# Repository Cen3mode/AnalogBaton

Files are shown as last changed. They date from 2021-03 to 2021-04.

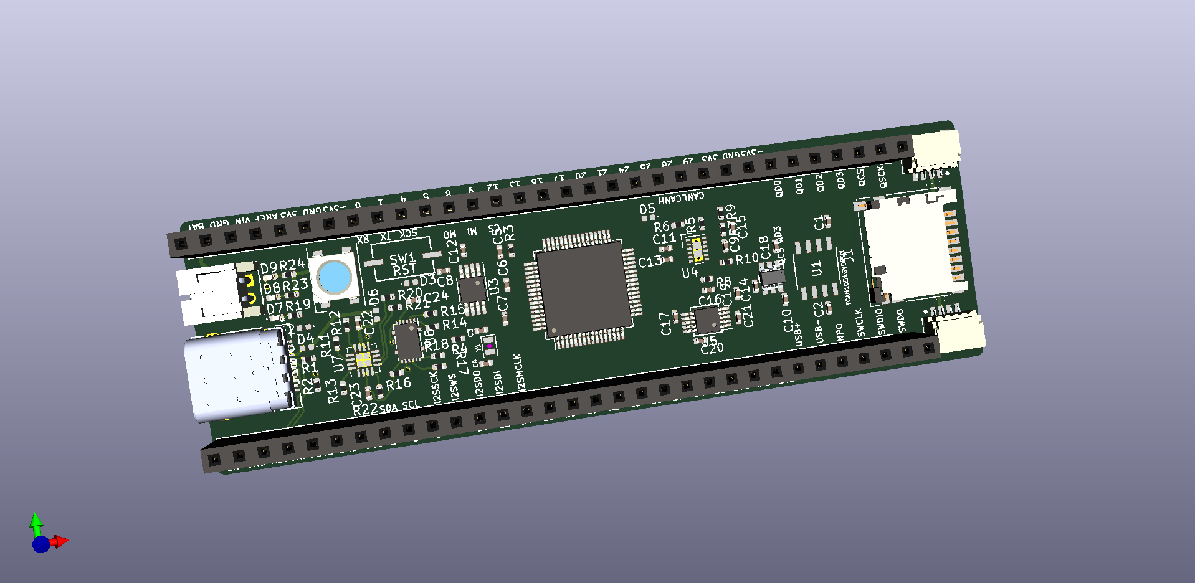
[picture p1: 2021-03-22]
pcbDesign/ATSAME51J18A-devboard.png

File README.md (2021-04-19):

TO DO:
	redo GPIO layout,
	redo SD card slot,
	get rid of CAN bus connector (leave broken out on pins),
	redo power from charge pumps to LDOs where possible for simplicity,
	make the board smaller,
	get rid of the cristall (using internal oscillator),
	choose USB-C port with only single row of pins,
	add M3 mounting holes,
	reconfigure charger and fuel gauge,
	add QSPI flash,

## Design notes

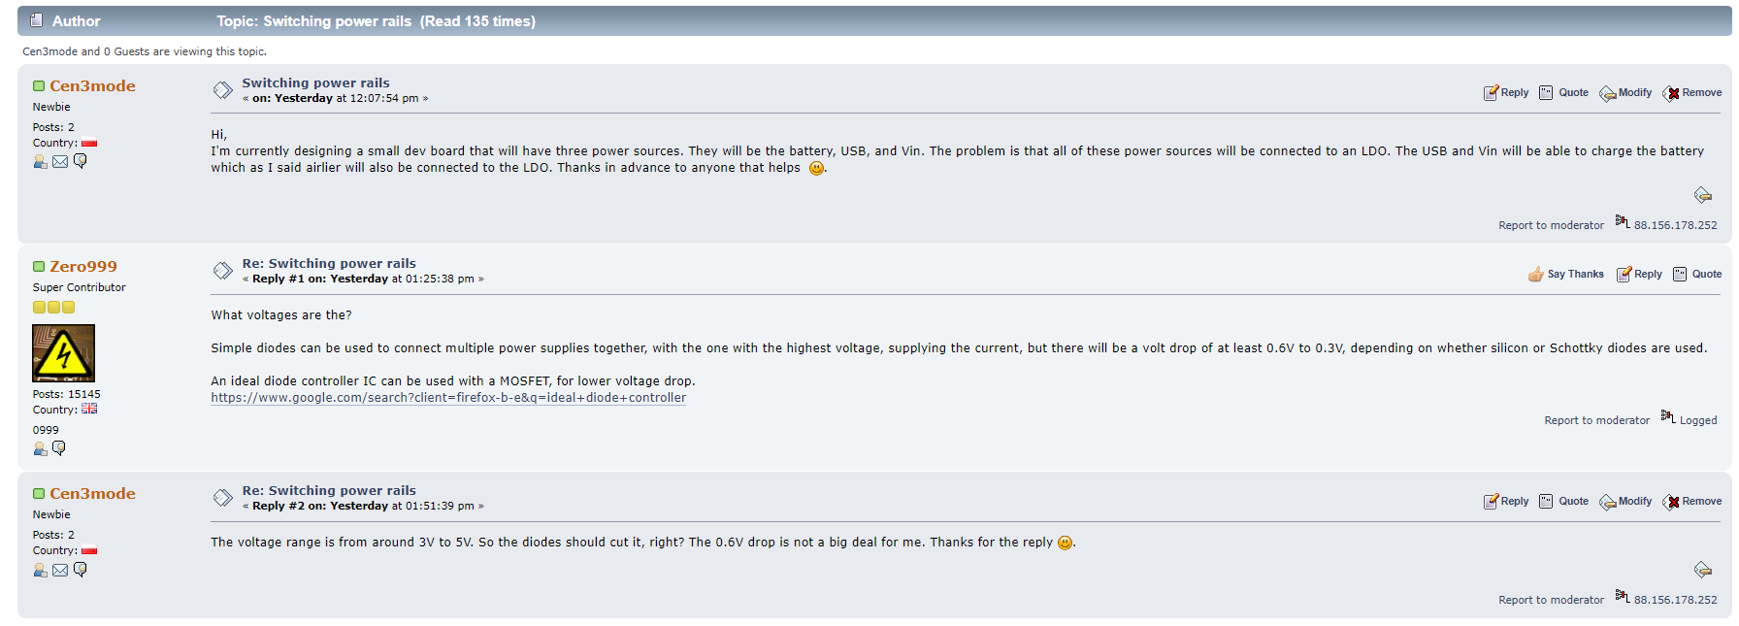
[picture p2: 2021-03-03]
forumDiscussionss/switchingPowerRails.PNG

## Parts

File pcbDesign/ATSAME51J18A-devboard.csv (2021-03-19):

Id | Oznaczenie | Obudowa | Ilość | Oznaczenie | Dostawca i numer artykułu
1 | U5 | MSOP-10_3x3mm_P0.5mm | 1 | TPS60501DGS | TPS60501DGSR
2 | J4 | JST_S2B-PH-K-S(LF)(SN) | 1 | S2B-PH-K-S(LF)(SN) | S2B-PH-K-S(LF)(SN)
3 | J2 | 12401598E4-2A | 1 | USB C | 12401598E4#2A
4 | IC1 | SOT95P280X100-6N | 1 | MP9361DJ-LF-P | MP9361DJ-LF-P
5 | SW1 | PTS636 SM25F SMTR LFS | 1 | RST | PTS636 SMG25J SMTR LFS
6 | J11,J7 | PinSocket_1x32_P2.54mm_Vertical | 2 | Conn_01x32_Male | 61303211121
7 | U2 | TQFP-64_10x10mm_P0.5mm | 1 | ATSAME51J18A-A | ATSAME51J18A-AUT
8 | J3 | JST_SM04B-SRSS-TB(LF)(SN) | 1 | QWIIC | SM04B-SRSS-TB(LF)(SN)
9 | R24,R23,R22,R21,R20,R5,R19,R18,R17,R6,R4,R3 | R_0402_1005Metric | 12 | 10k | RMCF0402JT10K0
10 | D9 | LED_0402_1005Metric | 1 | CHRG | APHHS1005CGCK
11 | Y1 | Crystal_SMD_2012-2Pin_2.0x1.2mm | 1 | 32.768 | ECS-.327-12.5-12-TR
12 | D8 | LED_0402_1005Metric | 1 | PWR | APHHS1005CGCK
13 | J10 | JST_SM04B-SRSS-TB(LF)(SN) | 1 | CAN | SM04B-SRSS-TB(LF)(SN)
14 | U8 | Texas_S-PDSO-N12 | 1 | BQ27441DRZR-G1B | BQ27441DRZR-G1B
15 | U7 | VQFN-16-1EP_3x3mm_P0.5mm_EP1.6x1.6mm | 1 | BQ24074RGT | BQ24074RGTT
16 | U4 | WSON-12-1EP_3x2mm_P0.5mm_EP1x2.65_ThermalVias | 1 | LM27762 | LM27762DSST
17 | U3 | MSOP-8_3x3mm_P0.65mm | 1 | MIC5219-5.0YMM | MIC5219-5.0YMM
18 | U1 | TCAN1051GVDRQ1 | 1 | TCAN1051GVDRQ1 | TCAN1051HVD
19 | R16 | R_0402_1005Metric | 1 | 0.01 | PE0402FRF070R01L
20 | R15,R14,R2,R1 | R_0402_1005Metric | 4 | 5.1k | RC0402FR-075K1L
21 | R13 | R_0402_1005Metric | 1 | 1.13k | RC0402FR-071K13L
22 | R12 | R_0402_1005Metric | 1 | 1.18k | RC0402FR-071K18L
23 | R11 | R_0402_1005Metric | 1 | 46.4k | RK73H1ETTP4642F
24 | R10,R9 | R_0402_1005Metric | 2 | 50k | RC1005F4992CS
25 | R8,R7 | R_0402_1005Metric | 2 | 87.5k | RC0402FR-0786K6L
27 | J1 | microSD_HC_Hirose_DM3D-SF | 1 | Micro_SD_Card | 5031821852
28 | D7 | LED_0402_1005Metric | 1 | LED | APHHS1005CGCK
29 | D6,D5,D4,D3,D2 | D_0402_1005Metric | 5 | D_Schottky | VSKY05301006-G4-08
30 | D1 | LED_WS2812B_PLCC4_5.0x5.0mm_P3.2mm | 1 | WS2812B | COM-16347
31 | C24,C14,C9,C8 | C_0402_1005Metric | 4 | 0.47u | GMC04X5R474K16NT
32 | C23,C22,C19,C13,C11 | C_0402_1005Metric | 5 | 4.7u | C1005X5R0J475M050BC
33 | C21,C17,C6,C5 | C_0402_1005Metric | 4 | 1u | CC0402KRX5R5BB105
34 | C20,C4,C3 | C_0402_1005Metric | 3 | 22u | CL05A226MQ6ZUN8
35 | C18 | C_0402_1005Metric | 1 | 10u | CL05A106MQ5NUNC
36 | C16,C15,C12,C10 | C_0402_1005Metric | 4 | 2.2u | C1005X7S1A225K050BC
37 | C7 | C_0402_1005Metric | 1 | 500n | GRM155R61A564KE15D
38 | C2,C1 | C_0402_1005Metric | 2 | 100n | GRM155R71C104KA88J

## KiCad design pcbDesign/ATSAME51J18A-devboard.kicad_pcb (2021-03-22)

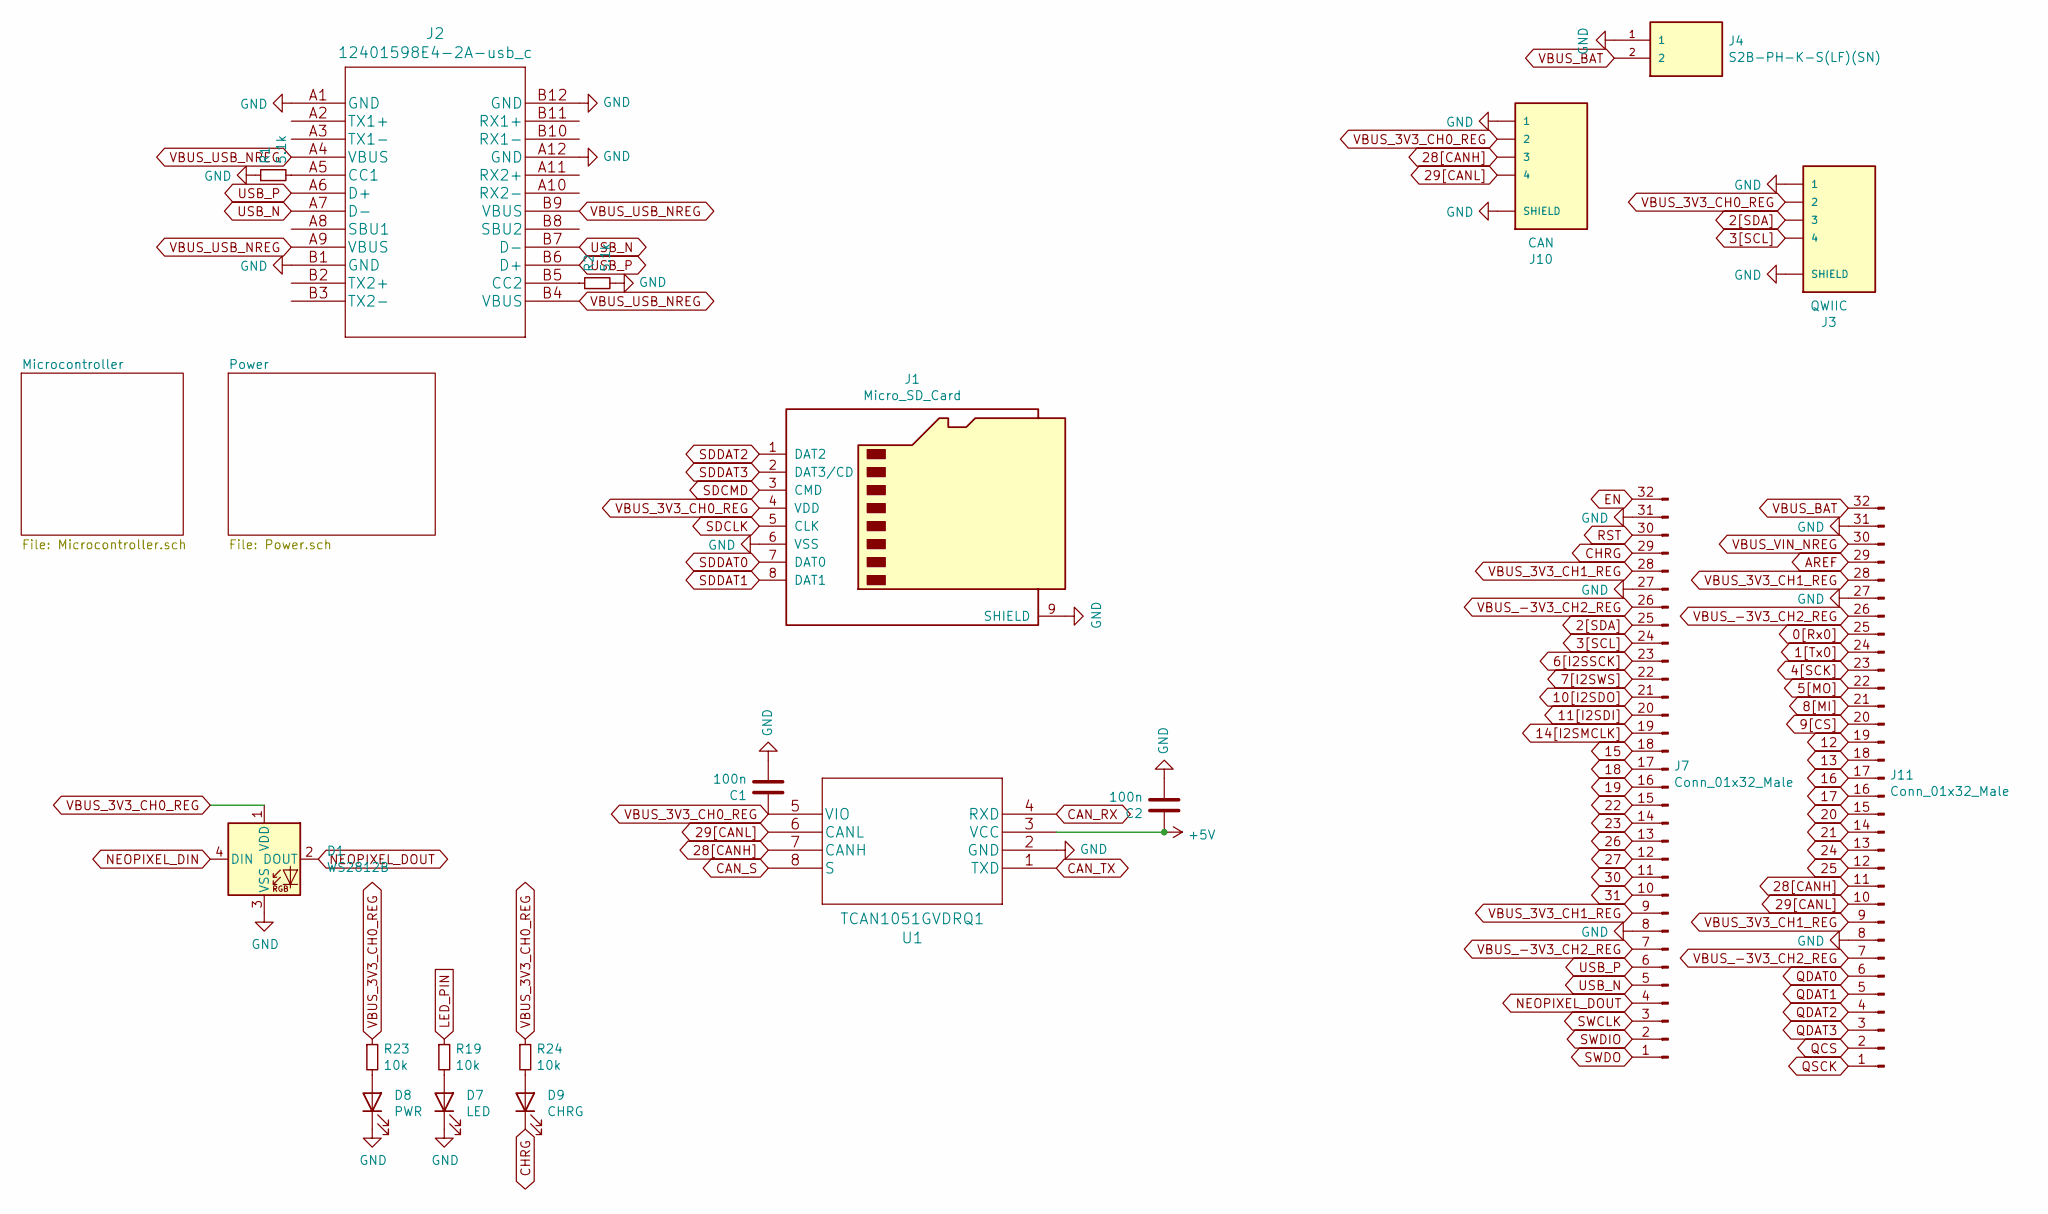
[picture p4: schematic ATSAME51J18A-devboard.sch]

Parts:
C1, C2: 100n; C_0402_1005Metric
D1: WS2812B; LED_WS2812B_PLCC4_5.0x5.0mm_P3.2mm
D7: LED; LED_0402_1005Metric
D8: PWR; LED_0402_1005Metric
D9: CHRG; LED_0402_1005Metric
J1: Micro_SD_Card; microSD_HC_Hirose_DM3D-SF
J2: 12401598E4-2A-usb_c; 12401598E4-2A
J3: QWIIC; JST_SM04B-SRSS-TB(LF)(SN)
J4: S2B-PH-K-S(LF)(SN); JST_S2B-PH-K-S(LF)(SN)
J7, J11: Conn_01x32_Male; PinSocket_1x32_P2.54mm_Vertical
J10: CAN; JST_SM04B-SRSS-TB(LF)(SN)
R1, R2: 5.1k; R_0402_1005Metric
R19, R23, R24: 10k; R_0402_1005Metric
U1: TCAN1051GVDRQ1

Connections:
0[Rx0]: J11.25; also elsewhere on the board
1[Tx0]: J11.24; also elsewhere on the board
2[SDA]: J3.3, J7.25; also elsewhere on the board
3[SCL]: J3.4, J7.24; also elsewhere on the board
4[SCK]: J1.5 (CLK), J11.23; also elsewhere on the board
5[MO]: J1.3 (CMD), J11.22; also elsewhere on the board
6[I2SSCK]: J7.23; also elsewhere on the board
7[I2SWS]: J7.22; also elsewhere on the board
8[MI]: J1.7 (DAT0), J11.21; also elsewhere on the board
9[CS]: J11.20; also elsewhere on the board
10[I2SDO]: J7.21; also elsewhere on the board
11[I2SDI]: J7.20; also elsewhere on the board
12: J11.19; also elsewhere on the board
13: J11.18, R19.1; also elsewhere on the board
14[I2SMCLK]: J7.19; also elsewhere on the board
15: J7.18; also elsewhere on the board
16: J11.17; also elsewhere on the board
17: J11.16; also elsewhere on the board
18: J7.17; also elsewhere on the board
19: J7.16; also elsewhere on the board
20: J11.15; also elsewhere on the board
21: J11.14; also elsewhere on the board
22: J7.15; also elsewhere on the board
23: J7.14; also elsewhere on the board
24: J11.13; also elsewhere on the board
25: J11.12; also elsewhere on the board
26: J7.13; also elsewhere on the board
27: J7.12; also elsewhere on the board
28[CANH]: J10.3, J11.11, U1.7 (CANH)
29[CANL]: J10.4, J11.10, U1.6 (CANL)
30: J7.11; also elsewhere on the board
31: J7.10; also elsewhere on the board
+5V: C2.2, U1.3 (VCC); also elsewhere on the board
AREF: J11.29; also elsewhere on the board
CAN_RX: U1.4 (RXD); also elsewhere on the board
CAN_S: U1.8 (S); also elsewhere on the board
CAN_TX: U1.1 (TXD); also elsewhere on the board
CHRG: D9.1 (K), J7.29; also elsewhere on the board
EN: J7.32; also elsewhere on the board
GND: C1.1, C2.1, D1.3 (VSS), D7.1 (K), D8.1 (K), J1.6 (VSS), J1.9 (SHIELD), J2.A1 (GND), J2.A12 (GND), J2.B1 (GND), J2.B12 (GND), J3.1, J3.S1 (SHIELD), J3.S2 (SHIELD), J4.1, J7.8, J7.27, J7.31, J10.1, J10.S1 (SHIELD), J10.S2 (SHIELD), J11.8, J11.27, J11.31, R1.1, R2.2, U1.2 (GND); also elsewhere on the board
NEOPIXEL_DIN: D1.4 (DIN); also elsewhere on the board
NEOPIXEL_DOUT: D1.2 (DOUT), J7.4
unnamed: D7.2 (A), R19.2
unnamed: D8.2 (A), R23.2
unnamed: D9.2 (A), R24.2
unnamed: J2.A5 (CC1), R1.2
unnamed: J2.B5 (CC2), R2.1
QCS: J11.2; also elsewhere on the board
QDAT0: J11.6; also elsewhere on the board
QDAT1: J11.5; also elsewhere on the board
QDAT2: J11.4; also elsewhere on the board
QDAT3: J11.3; also elsewhere on the board
QSCK: J11.1; also elsewhere on the board
RST: J7.30; also elsewhere on the board
SDDAT3: J1.2 (DAT3/CD); also elsewhere on the board
SWCLK: J7.3; also elsewhere on the board
SWDIO: J7.2; also elsewhere on the board
SWDO: J7.1; also elsewhere on the board
USB_N: J2.A7 (D-), J2.B7 (D-), J7.5; also elsewhere on the board
USB_P: J2.A6 (D+), J2.B6 (D+), J7.6; also elsewhere on the board
VBUS_3V3_CH0_REG: C1.2, D1.1 (VDD), J1.4 (VDD), J3.2, J10.2, R23.1, R24.1, U1.5 (VIO); also elsewhere on the board
VBUS_3V3_CH1_REG: J7.9, J7.28, J11.9, J11.28; also elsewhere on the board
VBUS_-3V3_CH2_REG: J7.7, J7.26, J11.7, J11.26; also elsewhere on the board
VBUS_BAT: J4.2, J11.32; also elsewhere on the board
VBUS_USB_NREG: J2.A4 (VBUS), J2.A9 (VBUS), J2.B4 (VBUS), J2.B9 (VBUS); also elsewhere on the board
VBUS_VIN_NREG: J11.30; also elsewhere on the board

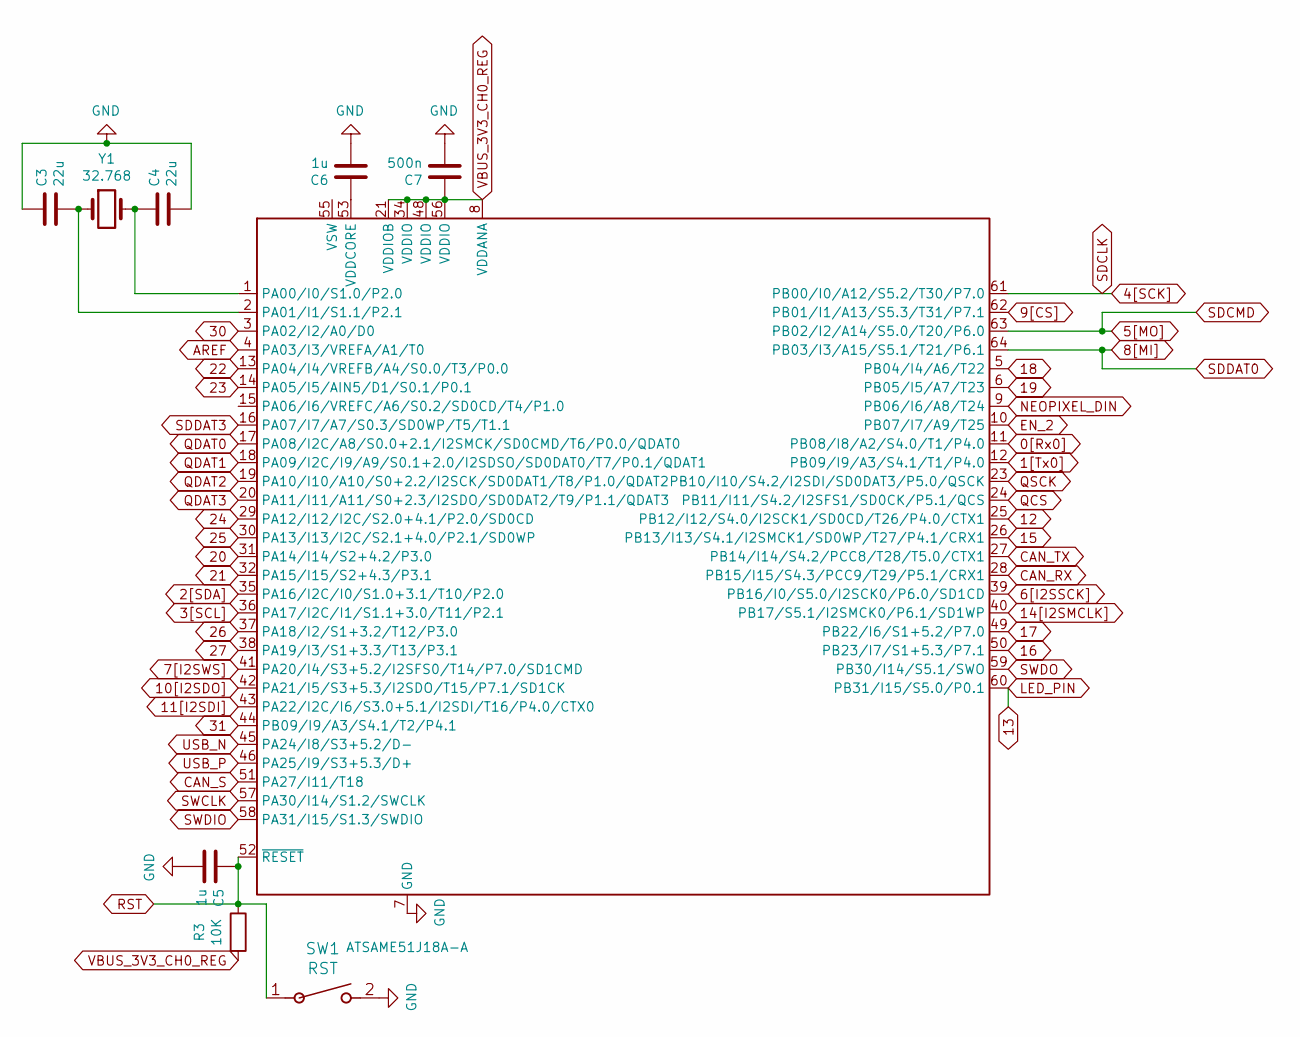
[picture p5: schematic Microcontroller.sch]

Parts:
C3, C4: 22u; C_0402_1005Metric
C5, C6: 1u; C_0402_1005Metric
C7: 500n; C_0402_1005Metric
R3: 10K; R_0402_1005Metric
SW1: RST; PTS636 SM25F SMTR LFS
U2: ATSAME51J18A-A; TQFP-64_10x10mm_P0.5mm
Y1: 32.768; Crystal_SMD_2012-2Pin_2.0x1.2mm

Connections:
0[Rx0]: U2.11 (PB08/I8/A2/S4.0/T1/P4.0); also elsewhere on the board
1[Tx0]: U2.12 (PB09/I9/A3/S4.1/T1/P4.0); also elsewhere on the board
2[SDA]: U2.35 (PA16/I2C/I0/S1.0+3.1/T10/P2.0); also elsewhere on the board
3[SCL]: U2.36 (PA17/I2C/I1/S1.1+3.0/T11/P2.1); also elsewhere on the board
4[SCK]: U2.61 (PB00/I0/A12/S5.2/T30/P7.0); also elsewhere on the board
5[MO]: U2.63 (PB02/I2/A14/S5.0/T20/P6.0); also elsewhere on the board
6[I2SSCK]: U2.39 (PB16/I0/S5.0/I2SCK0/P6.0/SD1CD); also elsewhere on the board
7[I2SWS]: U2.41 (PA20/I4/S3+5.2/I2SFS0/T14/P7.0/SD1CMD); also elsewhere on the board
8[MI]: U2.64 (PB03/I3/A15/S5.1/T21/P6.1); also elsewhere on the board
9[CS]: U2.62 (PB01/I1/A13/S5.3/T31/P7.1); also elsewhere on the board
10[I2SDO]: U2.42 (PA21/I5/S3+5.3/I2SDO/T15/P7.1/SD1CK); also elsewhere on the board
11[I2SDI]: U2.43 (PA22/I2C/I6/S3.0+5.1/I2SDI/T16/P4.0/CTX0); also elsewhere on the board
12: U2.25 (PB12/I12/S4.0/I2SCK1/SD0CD/T26/P4.0/CTX1); also elsewhere on the board
13: U2.60 (PB31/I15/S5.0/P0.1); also elsewhere on the board
14[I2SMCLK]: U2.40 (PB17/S5.1/I2SMCK0/P6.1/SD1WP); also elsewhere on the board
15: U2.26 (PB13/I13/S4.1/I2SMCK1/SD0WP/T27/P4.1/CR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); also elsewhere on the board
16: U2.50 (PB23/I7/S1+5.3/P7.1); also elsewhere on the board
17: U2.49 (PB22/I6/S1+5.2/P7.0); also elsewhere on the board
18: U2.5 (PB04/I4/A6/T22); also elsewhere on the board
19: U2.6 (PB05/I5/A7/T23); also elsewhere on the board
20: U2.31 (PA14/I14/S2+4.2/P3.0); also elsewhere on the board
21: U2.32 (PA15/I15/S2+4.3/P3.1); also elsewhere on the board
22: U2.13 (PA04/I4/VREFB/A4/S0.0/T3/P0.0); also elsewhere on the board
23: U2.14 (PA05/I5/AIN5/D1/S0.1/P0.1); also elsewhere on the board
24: U2.29 (PA12/I12/I2C/S2.0+4.1/P2.0/SD0CD); also elsewhere on the board
25: U2.30 (PA13/I13/I2C/S2.1+4.0/P2.1/SD0WP); also elsewhere on the board
26: U2.37 (PA18/I2/S1+3.2/T12/P3.0); also elsewhere on the board
27: U2.38 (PA19/I3/S1+3.3/T13/P3.1); also elsewhere on the board
30: U2.3 (PA02/I2/A0/D0); also elsewhere on the board
31: U2.44 (PB09/I9/A3/S4.1/T2/P4.1); also elsewhere on the board
AREF: U2.4 (PA03/I3/VREFA/A1/T0); also elsewhere on the board
CAN_RX: U2.28 (PB15/I15/S4.3/PCC9/T29/P5.1/CRX1); also elsewhere on the board
CAN_S: U2.51 (PA27/I11/T18); also elsewhere on the board
CAN_TX: U2.27 (PB14/I14/S4.2/PCC8/T28/T5.0/CTX1); also elsewhere on the board
EN_2: U2.10 (PB07/I7/A9/T25); also elsewhere on the board
GND: C3.2, C4.1, C5.1, C6.1, C7.1, SW1.2, U2.7 (GND), U2.22 (GND), U2.33 (GND), U2.47 (GND), U2.54 (GND); also elsewhere on the board
NEOPIXEL_DIN: U2.9 (PB06/I6/A8/T24); also elsewhere on the board
unnamed: C3.1, U2.2 (PA01/I1/S1.1/P2.1), Y1.1
unnamed: C4.2, U2.1 (PA00/I0/S1.0/P2.0), Y1.2
unnamed: C6.2, U2.53 (VDDCORE)
QCS: U2.24 (PB11/I11/S4.2/I2SFS1/SD0CK/P5.1/QCS); also elsewhere on the board
QDAT0: U2.17 (PA08/I2C/A8/S0.0+2.1/I2SMCK/SD0CMD/T6/P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); also elsewhere on the board
QDAT1: U2.18 (PA09/I2C/I9/A9/S0.1+2.0/I2SDSO/SD0DAT0/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); also elsewhere on the board
QDAT2: U2.19 (PA10/I10/A10/S0+2.2/I2SCK/SD0DAT1/T8/P1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); also elsewhere on the board
QDAT3: U2.20 (PA11/I11/A11/S0+2.3/I2SDO/SD0DAT2/T9/P1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); also elsewhere on the board
QSCK: U2.23 (PB10/I10/S4.2/I2SDI/SD0DAT3/P5.0/QSCK); also elsewhere on the board
RST: C5.2, R3.1, SW1.1, U2.52 (~RESET); also elsewhere on the board
SDDAT3: U2.16 (PA07/I7/A7/S0.3/SD0WP/T5/T1.1); also elsewhere on the board
SWCLK: U2.57 (PA30/I14/S1.2/SWCLK); also elsewhere on the board
SWDIO: U2.58 (PA31/I15/S1.3/SWDIO); also elsewhere on the board
SWDO: U2.59 (PB30/I14/S5.1/SWO); also elsewhere on the board
USB_N: U2.45 (PA24/I8/S3+5.2/D-); also elsewhere on the board
USB_P: U2.46 (PA25/I9/S3+5.3/D+); also elsewhere on the board
VBUS_3V3_CH0_REG: C7.2, R3.2, U2.8 (VDDANA), U2.21 (VDDIOB), U2.34 (VDDIO), U2.48 (VDDIO), U2.56 (VDDIO); also elsewhere on the board

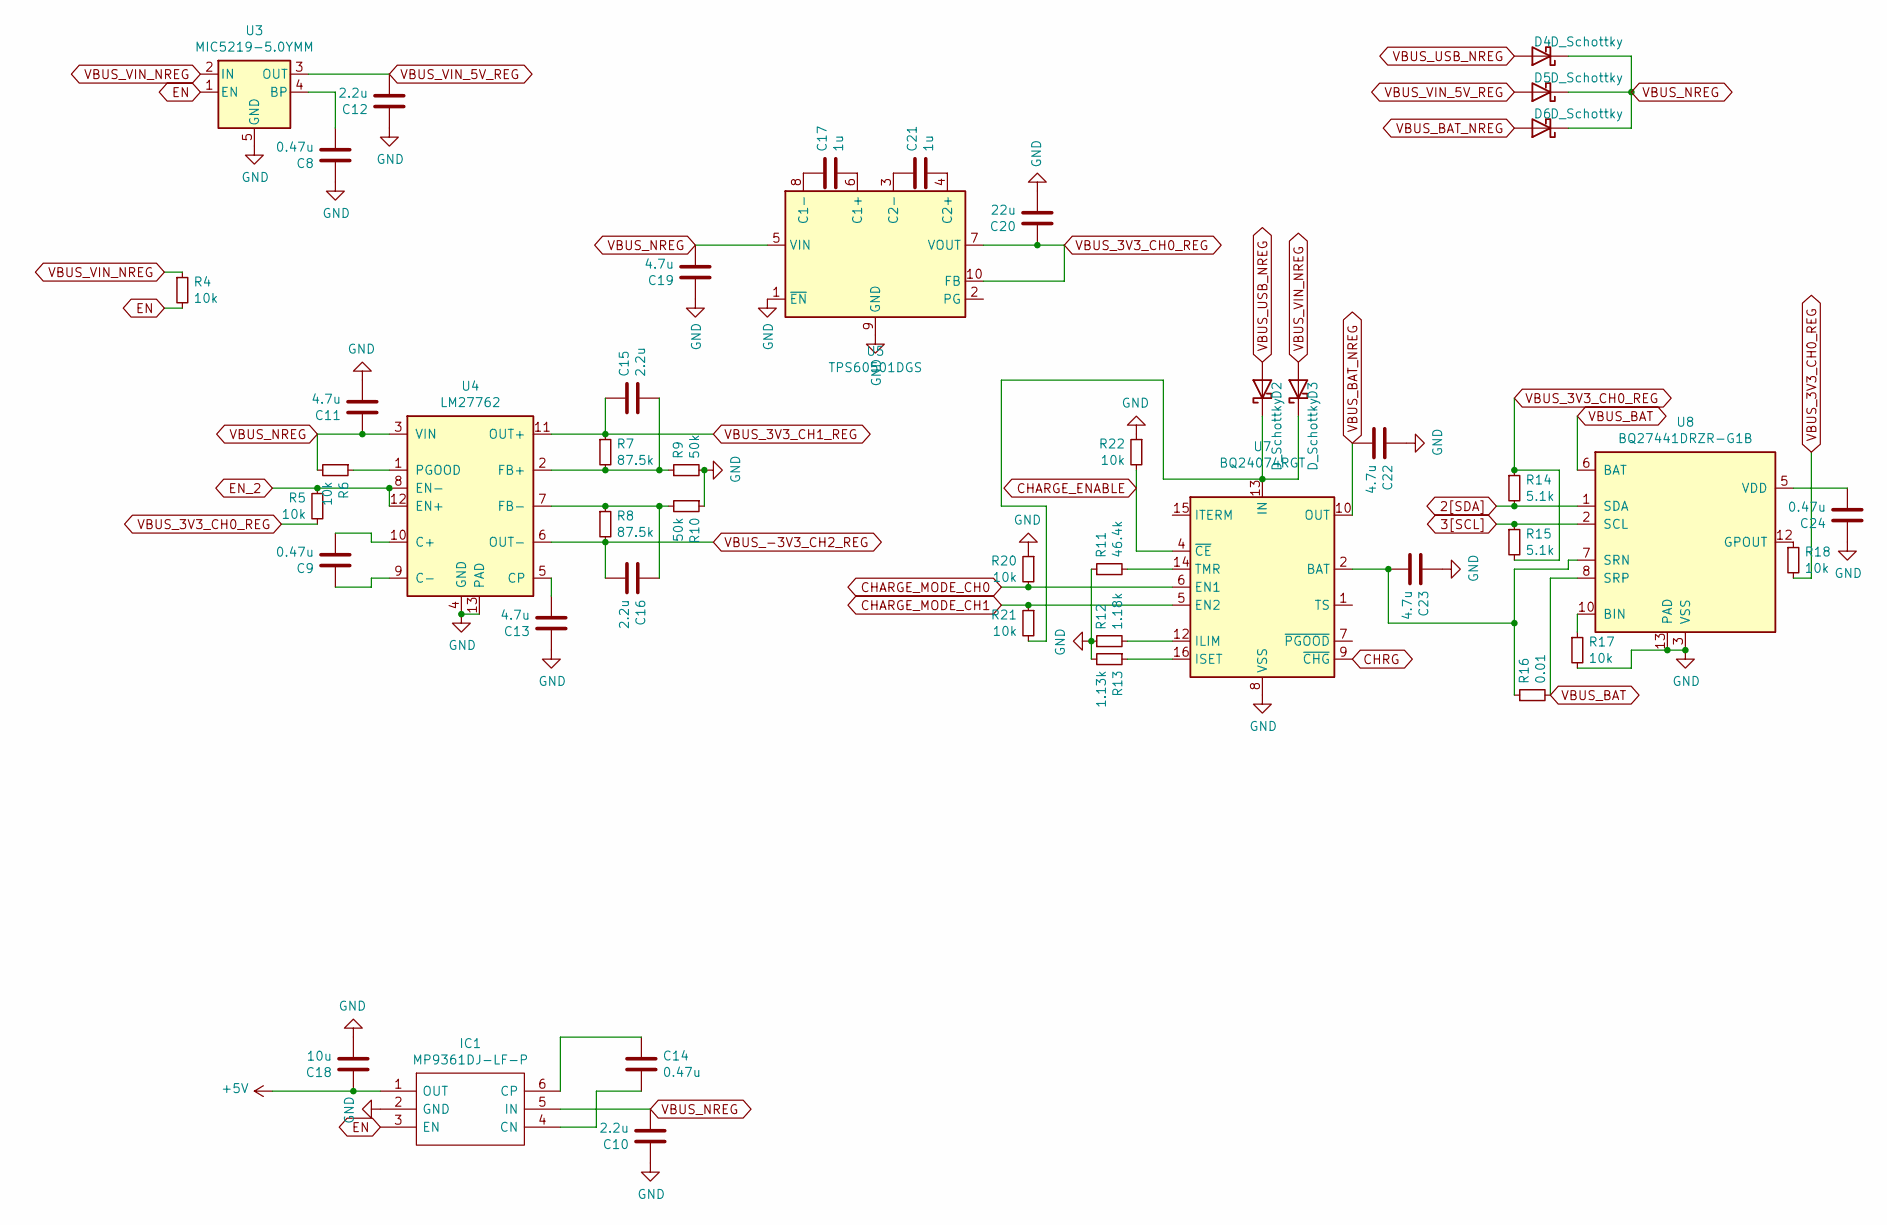
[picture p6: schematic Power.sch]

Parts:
C8, C9, C14, C24: 0.47u; C_0402_1005Metric
C10, C12, C15, C16: 2.2u; C_0402_1005Metric
C11, C13, C19, C22, C23: 4.7u; C_0402_1005Metric
C17, C21: 1u; C_0402_1005Metric
C18: 10u; C_0402_1005Metric
C20: 22u; C_0402_1005Metric
D2, D3, D4, D5, D6: D_Schottky; D_0402_1005Metric
IC1: MP9361DJ-LF-P; SOT95P280X100-6N; Mouser Part Number 946-MP9361DJLFP
R4, R5, R6, R17, R18, R20, R21, R22: 10k; R_0402_1005Metric
R7, R8: 87.5k; R_0402_1005Metric
R9, R10: 50k; R_0402_1005Metric
R11: 46.4k; R_0402_1005Metric
R12: 1.18k; R_0402_1005Metric
R13: 1.13k; R_0402_1005Metric
R14, R15: 5.1k; R_0402_1005Metric
R16: 0.01; R_0402_1005Metric
U3: MIC5219-5.0YMM; MSOP-8_3x3mm_P0.65mm
U4: LM27762; WSON-12-1EP_3x2mm_P0.5mm_EP1x2.65_ThermalVias
U5: TPS60501DGS; MSOP-10_3x3mm_P0.5mm
U7: BQ24074RGT; VQFN-16-1EP_3x3mm_P0.5mm_EP1.6x1.6mm
U8: BQ27441DRZR-G1B; Texas_S-PDSO-N12

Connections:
2[SDA]: R14.2, U8.1 (SDA); also elsewhere on the board
3[SCL]: R15.1, U8.2 (SCL); also elsewhere on the board
+5V: C18.2, IC1.1 (OUT); also elsewhere on the board
CHARGE_ENABLE: R22.2, U7.4 (~CE)
CHARGE_MODE_CH0: R20.2, U7.6 (EN1)
CHARGE_MODE_CH1: R21.1, U7.5 (EN2)
CHRG: U7.9 (~CHG); also elsewhere on the board
EN: IC1.3 (EN), R4.2, U3.1 (EN); also elsewhere on the board
EN_2: R5.1, U4.8 (EN-), U4.12 (EN+); also elsewhere on the board
GND: C8.2, C10.2, C11.1, C12.2, C13.2, C18.1, C19.2, C20.1, C22.2, C23.2, C24.2, IC1.2 (GND), R9.2, R10.1, R11.1, R12.1, R13.2, R17.2, R20.1, R22.1, U3.5 (GND), U3.6 (GND), U3.7 (GND), U3.8 (GND), U4.4 (GND), U4.13 (PAD), U5.1 (~EN), U5.9 (GND), U7.8 (VSS), U7.17 (VSS), U8.3 (VSS), U8.13 (PAD); also elsewhere on the board
unnamed: C8.1, U3.4 (BP)
unnamed: C9.1, U4.10 (C+)
unnamed: C9.2, U4.9 (C-)
unnamed: C13.1, U4.5 (CP)
unnamed: C14.1, IC1.4 (CN)
unnamed: C14.2, IC1.6 (CP)
unnamed: C15.1, R7.2, R9.1, U4.2 (FB+)
unnamed: C16.2, R8.1, R10.2, U4.7 (FB-)
unnamed: C17.1, U5.6 (C1+)
unnamed: C17.2, U5.8 (C1-)
unnamed: C21.1, U5.4 (C2+)
unnamed: C21.2, U5.3 (C2-)
unnamed: C23.1, R16.1, U7.2 (BAT), U7.3 (BAT), U8.7 (SRN)
unnamed: C24.1, U8.5 (VDD)
unnamed: D2.1 (K), D3.1 (K), R21.2, U7.13 (IN)
unnamed: R6.1, U4.1 (PGOOD)
unnamed: R11.2, U7.14 (TMR)
unnamed: R12.2, U7.12 (ILIM)
unnamed: R13.1, U7.16 (ISET)
unnamed: R17.1, U8.10 (BIN)
unnamed: R18.1, U8.12 (GPOUT)
VBUS_3V3_CH0_REG: C20.2, R5.2, R14.1, R15.2, R18.2, U5.7 (VOUT), U5.10 (FB); also elsewhere on the board
VBUS_3V3_CH1_REG: C15.2, R7.1, U4.11 (OUT+); also elsewhere on the board
VBUS_-3V3_CH2_REG: C16.1, R8.2, U4.6 (OUT-); also elsewhere on the board
VBUS_BAT: R16.2, U8.6 (BAT), U8.8 (SRP); also elsewhere on the board
VBUS_BAT_NREG: C22.1, D6.2 (A), U7.10 (OUT), U7.11 (OUT)
VBUS_NREG: C10.1, C11.2, C19.1, D4.1 (K), D5.1 (K), D6.1 (K), IC1.5 (IN), R6.2, U4.3 (VIN), U5.5 (VIN)
VBUS_USB_NREG: D2.2 (A), D4.2 (A); also elsewhere on the board
VBUS_VIN_5V_REG: C12.1, D5.2 (A), U3.3 (OUT)
VBUS_VIN_NREG: D3.2 (A), R4.1, U3.2 (IN); also elsewhere on the board

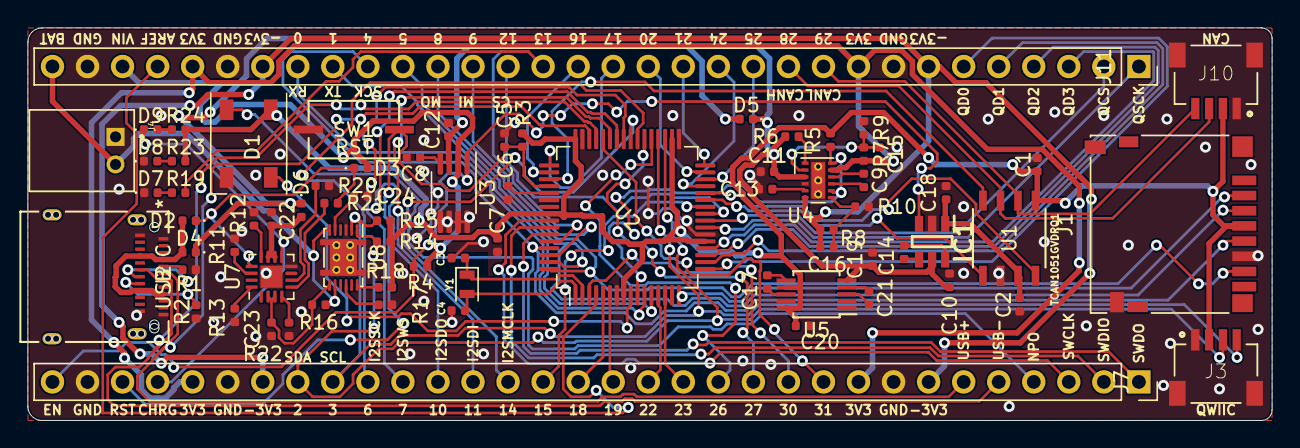
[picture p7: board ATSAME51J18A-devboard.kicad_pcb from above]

Board: 2 copper layers, 90.2 x 28.4 mm, 74 parts (0 on the bottom side), 97 nets.

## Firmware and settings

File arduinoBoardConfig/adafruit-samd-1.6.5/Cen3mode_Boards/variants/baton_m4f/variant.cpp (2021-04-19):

/*
  Copyright (c) 2014-2015 Arduino LLC.  All right reserved.

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
  You should have received a copy of the GNU Lesser General Public
  License along with this library; if not, write to the Free Software
  Foundation, Inc., 51 Franklin St, Fifth Floor, Boston, MA  02110-1301  USA
*/

#include "variant.h"
#include "Arduino.h"

/*
 * Pins descriptions
 */

//TCC0 IOSET 6
//TCC1 IOSET 1
//TC0 IOSET 1
//TC1 IOSET 1
//TC2 IOSET 2
//TC3 IOSET 1
//TC4 IOSET 1
const PinDescription g_APinDescription[PINS_COUNT]=
{
  { PORTB, 8, PIO_SERCOM, PIN_ATTR_PWM, No_ADC_Channel, TC4_CH0, NOT_ON_TIMER, EXTERNAL_INT_8 },       // D0 TX:  SERCOM4/PAD[0]
  { PORTB, 9, PIO_SERCOM, PIN_ATTR_PWM, No_ADC_Channel, TC4_CH1, NOT_ON_TIMER, EXTERNAL_INT_9 },       // D1 RX:  SERCOM4/PAD[1]
  { PORTA, 16, PIO_SERCOM, PIN_ATTR_PWM, No_ADC_Channel, TC2_CH0, TCC1_CH0, EXTERNAL_INT_0},           // D2 SDA:  SERCOM1/PAD[0]
  { PORTA, 17, PIO_SERCOM, PIN_ATTR_PWM, No_ADC_Channel, TC2_CH1, TCC1_CH1, EXTERNAL_INT_1},           // D3 SCL:  SERCOM1/PAD[1]
  { PORTB, 0, PIO_SERCOM, PIN_ATTR_DIGITAL, No_ADC_Channel, NOT_ON_PWM, NOT_ON_TIMER, EXTERNAL_INT_0}, // D4 MISO: SERCOM5/PAD[2]
  { PORTB, 2, PIO_SERCOM, PIN_ATTR_DIGITAL, No_ADC_Channel, NOT_ON_PWM, NOT_ON_TIMER, EXTERNAL_INT_2}, // D5 CS:   SERCOM5/PAD[0]
  { PORTB, 3, PIO_SERCOM, PIN_ATTR_DIGITAL, No_ADC_Channel, NOT_ON_PWM, NOT_ON_TIMER, EXTERNAL_INT_3}, // D8 MOSI: SERCOM5/PAD[1]
  { PORTB, 1, PIO_SERCOM, PIN_ATTR_DIGITAL, No_ADC_Channel, NOT_ON_PWM, NOT_ON_TIMER, EXTERNAL_INT_1}, // D9 SCK:  SERCOM5/PAD[3]
  { PORTB, 16, PIO_DIGITAL, PIN_ATTR_PWM, No_ADC_Channel, TC6_CH0, TCC0_CH4, EXTERNAL_INT_0},          // D6
  { PORTA, 20, PIO_DIGITAL, PIN_ATTR_PWM, No_ADC_Channel, TC7_CH0, TCC0_CH0, EXTERNAL_INT_4},          // D7
  { PORTA, 21, PIO_DIGITAL, PIN_ATTR_PWM, No_ADC_Channel, TC7_CH1, TCC1_CH5, EXTERNAL_INT_5},          // D10
  { PORTA, 22, PIO_DIGITAL, PIN_ATTR_PWM, No_ADC_Channel, TC4_CH0, TCC1_CH6, EXTERNAL_INT_6},          // D11
  { PORTB, 12, PIO_DIGITAL, PIN_ATTR_PWM, No_ADC_Channel, TC4_CH0, NOT_ON_TIMER, EXTERNAL_INT_12},     // D12
  { PORTB, 31, PIO_DIGITAL, PIN_ATTR_PWM, No_ADC_Channel, TC0_CH1, TCC0_CH6, EXTERNAL_INT_15},         // D13
  { PORTB, 17, PIO_DIGITAL, PIN_ATTR_PWM, No_ADC_Channel, TC6_CH1, NOT_ON_TIMER, EXTERNAL_INT_NONE},    // D14
  { PORTB, 13, PIO_DIGITAL, PIN_ATTR_PWM, No_ADC_Channel, TC4_CH1, TCC3_CH1, EXTERNAL_INT_13},         // D15
  { PORTB, 23, PIO_DIGITAL, PIN_ATTR_PWM, No_ADC_Channel, TC7_CH1, NOT_ON_TIMER, EXTERNAL_INT_7},      // D16
  { PORTB, 22, PIO_DIGITAL, PIN_ATTR_PWM, No_ADC_Channel, TC7_CH0, NOT_ON_TIMER, EXTERNAL_INT_6},      // D17
  { PORTB, 4, PIO_ANALOG, PIN_ATTR_ANALOG | PIN_ATTR_PWM, ADC_Channel7, NOT_ON_PWM, NOT_ON_TIMER, EXTERNAL_INT_4},    // D18
  { PORTB, 5, PIO_ANALOG, PIN_ATTR_ANALOG | PIN_ATTR_PWM, ADC_channel14, NOT_ON_PWM, NOT_ON_TIMER, EXTERNAL_INT_5},    // D19
  { PORTA, 14, PIO_DIGITAL, PIN_ATTR_PWM, No_ADC_Channel, TC3_CH0, NOT_ON_TIMER, EXTERNAL_INT_14},     // D20
  { PORTA, 15, PIO_DIGITAL, PIN_ATTR_PWM, No_ADC_Channel, TC3_CH1, NOT_ON_TIMER, EXTERNAL_INT_15},     // D21
  { PORTA, 4, PIO_ANALOG, PIN_ATTR_ANALOG | PIN_ATTR_PWM, ADC_Channel4, TC0_CH0, NOT_ON_TIMER, EXTERNAL_INT_4},       // D22
  { PORTA, 5, PIO_ANALOG, PIN_ATTR_ANALOG | PIN_ATTR_PWM, ADC_Channel5, TC0_CH1, NOT_ON_TIMER, EXTERNAL_INT_5},       // D23
  { PORTA, 12, PIO_DIGITAL, PIN_ATTR_PWM, No_ADC_Channel, TC2_CH0, NOT_ON_TIMER, EXTERNAL_INT_12},     // D24
  { PORTA, 13, PIO_DIGITAL, PIN_ATTR_PWM, No_ADC_Channel, TC2_CH1, NOT_ON_TIMER, EXTERNAL_INT_13},     // D25
  { PORTA, 18, PIO_DIGITAL, PIN_ATTR_PWM, No_ADC_Channel, TC3_CH0, NOT_ON_TIMER, EXTERNAL_INT_2},      // D26
  { PORTA, 19, PIO_DIGITAL, PIN_ATTR_PWM, No_ADC_Channel, TC3_CH1, NOT_ON_TIMER, EXTERNAL_INT_3},      // D27
  { PORTA, 2, PIO_ANALOG, PIN_ATTR_ANALOG | PIN_ATTR_PWM, ADC_Channel0, NOT_ON_PWM, NOT_ON_TIMER, EXTERNAL_INT_2},    // D28
  { PORTA, 23, PIO_DIGITAL, PIN_ATTR_PWM, No_ADC_Channel, TC4_CH1, TCC1_CH6, EXTERNAL_INT_7},          // D29

  { PORTB, 6, PIO_DIGITAL, PIN_ATTR_DIGITAL, No_ADC_Channel, NOT_ON_PWM, NOT_ON_TIMER, EXTERNAL_INT_NONE},          // NEOPIXEL


  { PORTA, 24, PIO_COM, PIN_ATTR_NONE, No_ADC_Channel, NOT_ON_PWM, NOT_ON_TIMER, EXTERNAL_INT_NONE }, // USB/DM
  { PORTA, 25, PIO_COM, PIN_ATTR_NONE, No_ADC_Channel, NOT_ON_PWM, NOT_ON_TIMER, EXTERNAL_INT_NONE }, // USB/DP

  { PORTA, 3, PIO_ANALOG, PIN_ATTR_ANALOG, No_ADC_Channel, NOT_ON_PWM, NOT_ON_TIMER, EXTERNAL_INT_NONE }, // DAC/VREFP

  { PORTA,  2, PIO_ANALOG, PIN_ATTR_ANALOG, DAC_Channel0, NOT_ON_PWM, NOT_ON_TIMER, EXTERNAL_INT_NONE }, // DAC/VOUT0
  { PORTA,  5, PIO_ANALOG, PIN_ATTR_ANALOG, DAC_Channel1, NOT_ON_PWM, NOT_ON_TIMER, EXTERNAL_INT_NONE }, // DAC/VOUT1

  { PORTB, 10, PIO_COM, PIN_ATTR_NONE, No_ADC_Channel, NOT_ON_PWM, NOT_ON_TIMER, EXTERNAL_INT_NONE }, //QSCK
  { PORTB, 11, PIO_COM, PIN_ATTR_NONE, No_ADC_Channel, NOT_ON_PWM, NOT_ON_TIMER, EXTERNAL_INT_NONE }, //QCS
  { PORTA, 8, PIO_COM, PIN_ATTR_NONE, No_ADC_Channel, NOT_ON_PWM, NOT_ON_TIMER, EXTERNAL_INT_NONE }, //QD0
  { PORTA, 9, PIO_COM, PIN_ATTR_NONE, No_ADC_Channel, NOT_ON_PWM, NOT_ON_TIMER, EXTERNAL_INT_NONE }, //QD1
  { PORTA, 10, PIO_COM, PIN_ATTR_NONE, No_ADC_Channel, NOT_ON_PWM, NOT_ON_TIMER, EXTERNAL_INT_NONE }, //QD2
  { PORTA, 11, PIO_COM, PIN_ATTR_NONE, No_ADC_Channel, NOT_ON_PWM, NOT_ON_TIMER, EXTERNAL_INT_NONE }, //QD3

  { PORTA, 27, PIO_DIGITAL, PIN_ATTR_NONE, No_ADC_Channel, NOT_ON_PWM, NOT_ON_TIMER, EXTERNAL_INT_NONE }, // CAN S
  { PORTB, 14, PIO_COM, PIN_ATTR_NONE, No_ADC_Channel, NOT_ON_PWM, NOT_ON_TIMER, EXTERNAL_INT_NONE }, // CAN TX
  { PORTB, 15, PIO_COM, PIN_ATTR_NONE, No_ADC_Channel, NOT_ON_PWM, NOT_ON_TIMER, EXTERNAL_INT_NONE }, // CAN RX
} ;

const void* g_apTCInstances[TCC_INST_NUM+TC_INST_NUM]={ TCC0, TCC1, TCC2, TCC3, TCC4, TC0, TC1, TC2, TC3, TC4, TC5 } ;
const uint32_t GCLK_CLKCTRL_IDs[TCC_INST_NUM+TC_INST_NUM] = { TCC0_GCLK_ID, TCC1_GCLK_ID, TCC2_GCLK_ID, TCC3_GCLK_ID, TCC4_GCLK_ID, TC0_GCLK_ID, TC1_GCLK_ID, TC2_GCLK_ID, TC3_GCLK_ID, TC4_GCLK_ID, TC5_GCLK_ID } ;

// Multi-serial objects instantiation
SERCOM sercom0( SERCOM0 ) ;
SERCOM sercom1( SERCOM1 ) ;
SERCOM sercom2( SERCOM2 ) ;
SERCOM sercom3( SERCOM3 ) ;
SERCOM sercom4( SERCOM4 ) ;
SERCOM sercom5( SERCOM5 ) ;

Uart Serial1( &sercom5, PIN_SERIAL1_RX, PIN_SERIAL1_TX, PAD_SERIAL1_RX, PAD_SERIAL1_TX ) ;

void SERCOM5_0_Handler()
{
  Serial1.IrqHandler();
}
void SERCOM5_1_Handler()
{
  Serial1.IrqHandler();
}
void SERCOM5_2_Handler()
{
  Serial1.IrqHandler();
}
void SERCOM5_3_Handler()
{
  Serial1.IrqHandler();
}

void initVariant(void);

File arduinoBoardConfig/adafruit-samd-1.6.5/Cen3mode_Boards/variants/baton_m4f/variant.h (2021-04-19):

/*
  Copyright (c) 2014-2015 Arduino LLC.  All right reserved.

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
  You should have received a copy of the GNU Lesser General Public
  License along with this library; if not, write to the Free Software
  Foundation, Inc., 51 Franklin St, Fifth Floor, Boston, MA  02110-1301  USA
*/

#ifndef _VARIANT_BATON_M4F_
#define _VARIANT_BATON_M4F_

// The definitions here needs a SAMD core >=1.6.10
#define ARDUINO_SAMD_VARIANT_COMPLIANCE 10610

/*----------------------------------------------------------------------------
 *        Definitions
 *----------------------------------------------------------------------------*/

/** Frequency of the board main oscillator */
#define VARIANT_MAINOSC		(32768ul)

/** Master clock frequency */
#define VARIANT_MCK        (F_CPU)

#define VARIANT_GCLK0_FREQ (F_CPU)
#define VARIANT_GCLK1_FREQ (48000000UL)
#define VARIANT_GCLK2_FREQ (100000000UL)

/*----------------------------------------------------------------------------
 *        Headers
 *----------------------------------------------------------------------------*/

#include "WVariant.h"

#ifdef __cplusplus
#include "SERCOM.h"
#include "Uart.h"
#endif // __cplusplus

#ifdef __cplusplus
extern "C"
{
#endif // __cplusplus

/*----------------------------------------------------------------------------
 *        Pins
 *----------------------------------------------------------------------------*/

// Number of pins defined in PinDescription array
#define PINS_COUNT           (44u)
#define NUM_DIGITAL_PINS     (30u)
#define NUM_ANALOG_INPUTS    (5u)
#define NUM_ANALOG_OUTPUTS   (2u)
#define analogInputToDigitalPin(p)  ((p < 6u) ? (p) + 14u : -1)

#define digitalPinToPort(P)        ( &(PORT->Group[g_APinDescription[P].ulPort]) )
#define digitalPinToBitMask(P)     ( 1 << g_APinDescription[P].ulPin )
//#define analogInPinToBit(P)        ( )
#define portOutputRegister(port)   ( &(port->OUT.reg) )
#define portInputRegister(port)    ( &(port->IN.reg) )
#define portModeRegister(port)     ( &(port->DIR.reg) )
#define digitalPinHasPWM(P)        ( g_APinDescription[P].ulPWMChannel != NOT_ON_PWM || g_APinDescription[P].ulTCChannel != NOT_ON_TIMER )

/*
 * digitalPinToTimer(..) is AVR-specific and is not defined for SAMD
 * architecture. If you need to check if a pin supports PWM you must
 * use digitalPinHasPWM(..).
 *
 * https://github.com/arduino/Arduino/issues/1833
 */
// #define digitalPinToTimer(P)

// LEDs
#define PIN_LED_13           (13u)
#define PIN_LED              PIN_LED_13
#define LED_BUILTIN          PIN_LED_13
#define PIN_NEOPIXEL         (31)

/*
 * Analog pins
 */
#define PIN_A0               (18ul)
#define PIN_A1               (19ul)
#define PIN_A2               (22ul)
#define PIN_A3               (23ul)
#define PIN_A4               (28ul)

#define PIN_DAC0             (34ul)
#define PIN_DAC1             (35ul)

static const uint8_t A0  = PIN_A0;
static const uint8_t A1  = PIN_A1;
static const uint8_t A2  = PIN_A2;
static const uint8_t A3  = PIN_A3;
static const uint8_t A4  = PIN_A4;

static const uint8_t DAC0 = PIN_DAC0;
static const uint8_t DAC1 = PIN_DAC1;

#define ADC_RESOLUTION		12

/*
 * Serial interfaces
 */

// Serial1
#define PIN_SERIAL1_RX       (1ul)
#define PIN_SERIAL1_TX       (0ul)
#define PAD_SERIAL1_RX       (SERCOM_RX_PAD_1)
#define PAD_SERIAL1_TX       (UART_TX_PAD_0)

/*
 * SPI Interfaces
 */
#define SPI_INTERFACES_COUNT 1

#define PIN_SPI_MISO         (4u)
#define PIN_SPI_MOSI         (6u)
#define PIN_SPI_SCK          (9u)
#define PIN_SPI_CS           (5u)
#define PERIPH_SPI           sercom5
#define PAD_SPI_TX           SPI_PAD_3_SCK_1
#define PAD_SPI_RX           SERCOM_RX_PAD_2

static const uint8_t SS	  = PIN_SPI_CS ;	
static const uint8_t MOSI = PIN_SPI_MOSI ;
static const uint8_t MISO = PIN_SPI_MISO ;
static const uint8_t SCK  = PIN_SPI_SCK ;

/*
 * Wire Interfaces
 */
#define WIRE_INTERFACES_COUNT 1

#define PIN_WIRE_SDA         (2u)
#define PIN_WIRE_SCL         (3u)
#define PERIPH_WIRE          sercom1
#define WIRE_IT_HANDLER      SERCOM1_Handler
#define WIRE_IT_HANDLER_0    SERCOM1_0_Handler
#define WIRE_IT_HANDLER_1    SERCOM1_1_Handler
#define WIRE_IT_HANDLER_2    SERCOM1_2_Handler
#define WIRE_IT_HANDLER_3    SERCOM1_3_Handler

static const uint8_t SDA = PIN_WIRE_SDA;
static const uint8_t SCL = PIN_WIRE_SCL;

/*
 * USB
 */
//#define PIN_USB_HOST_ENABLE (28ul)
#define PIN_USB_DM          (32ul)
#define PIN_USB_DP          (33ul)

/*
 * I2S Interfaces
 */
// #define I2S_INTERFACES_COUNT 1

// #define I2S_DEVICE          0
// #define I2S_CLOCK_GENERATOR 3

// #define PIN_I2S_SDO          (11u)
// #define PIN_I2S_SDI          (12u)
// #define PIN_I2S_SCK          PIN_SERIAL1_TX
// #define PIN_I2S_FS           (10u)
// #define PIN_I2S_MCK          PIN_SERIAL1_RX

// On-board QSPI Flash
// #define EXTERNAL_FLASH_DEVICES   GD25Q16C
// #define EXTERNAL_FLASH_USE_QSPI

//QSPI Pins
#define PIN_QSPI_SCK    (34u)
#define PIN_QSPI_CS     (35u)
#define PIN_QSPI_IO0    (36u)
#define PIN_QSPI_IO1    (37u)
#define PIN_QSPI_IO2    (38u)
#define PIN_QSPI_IO3    (39u)

#if !defined(VARIANT_QSPI_BAUD_DEFAULT)
  // TODO: meaningful value for this
  #define VARIANT_QSPI_BAUD_DEFAULT 5000000
#endif

/*
 * CAN
 */
#define PIN_CAN_STANDBY (41)
#define PIN_CAN_TX      (42)
#define PIN_CAN_RX      (43)

// #define PIN_CAN1_TX     (12)
// #define PIN_CAN1_RX     (13)


#ifdef __cplusplus
}
#endif

/*----------------------------------------------------------------------------
 *        Arduino objects - C++ only
 *----------------------------------------------------------------------------*/

#ifdef __cplusplus

/*	=========================
 *	===== SERCOM DEFINITION
 *	=========================
*/
extern SERCOM sercom0;
extern SERCOM sercom1;
extern SERCOM sercom2;
extern SERCOM sercom3;
extern SERCOM sercom4;
extern SERCOM sercom5;

extern Uart Serial1;

#endif

// These serial port names are intended to allow libraries and architecture-neutral
// sketches to automatically default to the correct port name for a particular type
// of use.  For example, a GPS module would normally connect to SERIAL_PORT_HARDWARE_OPEN,
// the first hardware serial port whose RX/TX pins are not dedicated to another use.
//
// SERIAL_PORT_MONITOR        Port which normally prints to the Arduino Serial Monitor
//
// SERIAL_PORT_USBVIRTUAL     Port which is USB virtual serial
//
// SERIAL_PORT_LINUXBRIDGE    Port which connects to a Linux system via Bridge library
//
// SERIAL_PORT_HARDWARE       Hardware serial port, physical RX & TX pins.
//
// SERIAL_PORT_HARDWARE_OPEN  Hardware serial ports which are open for use.  Their RX & TX
//                            pins are NOT connected to anything by default.
#define SERIAL_PORT_USBVIRTUAL      Serial
#define SERIAL_PORT_MONITOR         Serial
// Serial has no physical pins broken out, so it's not listed as HARDWARE port
#define SERIAL_PORT_HARDWARE        Serial1
#define SERIAL_PORT_HARDWARE_OPEN   Serial1

#endif /* _VARIANT_FEATHER_M4_ */

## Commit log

2021-03-03 Moved cicruit designes to the repo
    [ATSAME51J18A-devboard.kicad_pcb, ATSAME51J18A-devboard.sch]
2021-03-03 Configured battery gas gauge
2021-03-05 Finished schematic v0.1
    [ATSAME51J18A-devboard.sch, Microcontroller.sch, Power.sch]
2021-03-05 Cerrected errors in the schematic and began work on the pcb layout
    [ATSAME51J18A-devboard.sch, Microcontroller.sch, Power.sch]
2021-03-06 Fixed power rail enabling systems and rearanged pins for easier use
    [ATSAME51J18A-devboard.kicad_pcb, ATSAME51J18A-devboard.sch, Power.sch]
2021-03-07 Changed pin pitch to 2.54mm
    [ATSAME51J18A-devboard.kicad_pcb, ATSAME51J18A-devboard.sch]
2021-03-10 Finnished routing
    [ATSAME51J18A-devboard.dsn, ATSAME51J18A-devboard.kicad_pcb, ATSAME51J18A-devboard.sch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]
2021-03-10 Panelized the design
    [ATSAME51J18A-devboard-panel.kicad_pcb, ATSAME51J18A-devboardTSAME51J18A-devboard-panel.kicad_pcb]
2021-03-11 Labeled pins done
    [ATSAME51J18A-devboard.kicad_pcb]
2021-03-11 Repanelized board after adding pin descriptions
    [ATSAME51J18A-devboard-panel.kicad_pcb, ATSAME51J18A-devboard.kicad_pcb, arduino_zero.cfg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]
2021-03-12 Changed the layout of pins to make room for SWD and made the board longer
    [ATSAME51J18A-devboard.dsn, ATSAME51J18A-devboard.kicad_pcb, ATSAME51J18A-devboard.sch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]
2021-03-13 Corrected pin header spacing to fit on a bread board
    [ATSAME51J18A-devboard.dsn, ATSAME51J18A-devboard.kicad_pcb]
2021-03-13 Panelized the final design
    [ATSAME51J18A-devboard-panel.kicad_pcb, ATSAME51J18A-devboard.csv]
2021-03-14 Reconfigured charging circuit
    [ATSAME51J18A-devboard.kicad_pcb, Power.sch]
2021-03-14 Generated bom file
    [ATSAME51J18A-devboard.csv]
2021-03-15 Rewired SD card to SPI for ease of use
    [ATSAME51J18A-devboard.dsn, ATSAME51J18A-devboard.kicad_pcb, Microcontroller.sch]
2021-03-16 Started routing manually
    [ATSAME51J18A-devboard.dsn, ATSAME51J18A-devboard.kicad_pcb]
2021-03-17 Contnueing routing
    [ATSAME51J18A-devboard.kicad_pcb]
2021-03-18 Finnished routing for the prototype(v0.1)
    [ATSAME51J18A-devboard.kicad_pcb]
2021-03-18 Panelized the prototype(v0.1)
    [ATSAME51J18A-devboard-panel.kicad_pcb]
2021-03-18 Fixed panelizing issues
    [ATSAME51J18A-devboard-panel.kicad_pcb]
2021-03-19 Swapped components for more avaiable ones
    [ATSAME51J18A-devboard.csv, ATSAME51J18A-devboard.kicad_pcb, ATSAME51J18A-devboard.sch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]
2021-03-19 Generated new BOM file
    [ATSAME51J18A-devboard-old.csv, ATSAME51J18A-devboard.csv]
2021-03-19 Added logo
    [ATSAME51J18A-devboard.kicad_pcb]
2021-03-19 Panelized with logo
    [ATSAME51J18A-devboard-panel.kicad_pcb]
2021-03-19 Finnished final BOM file
    [ATSAME51J18A-devboard.csv]
2021-03-20 Fixed some DRC errors
    [ATSAME51J18A-devboard-panel.kicad_pcb, ATSAME51J18A-devboard.kicad_pcb]
2021-03-21 Fabrication files
    [ATSAME51J18A-devboard-panel-B_Cu.gbr, ATSAME51J18A-devboard-panel-B_Mask.gbr, ATSAME51J18A-devboard-panel-B_Paste.gbr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]
2021-03-22 Finnished routing board prototype(v0.2)
    [ATSAME51J18A-devboard-panel-B_Cu.gbr, ATSAME51J18A-devboard-panel-B_Mask.gbr, ATSAME51J18A-devboard-panel-B_Paste.gbr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]
2021-03-22 Panelised prototype(v0.2)
    [ATSAME51J18A-devboard-panel.kicad_pcb]
2021-03-22 Generated gerber files for prototype(v0.2)
    [ATSAME51J18A-devboard-panel-B_Cu.gbr, ATSAME51J18A-devboard-panel-B_Mask.gbr, ATSAME51J18A-devboard-panel-B_Paste.gbr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]
2021-04-16 Some arduino configs
2021-04-19 Begun to make changes to the design
    [ATSAME51J18A-devboard.sch, Microcontroller.sch, Power.sch]

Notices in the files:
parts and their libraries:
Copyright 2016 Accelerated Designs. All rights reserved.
